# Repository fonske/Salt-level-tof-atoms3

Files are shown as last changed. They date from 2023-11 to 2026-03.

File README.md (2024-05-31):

# Salt-level-tof-atoms3-lite
   Salt level detection brine tank water softener with TOF sensor and AtomS3 lite M5stack
   
   Zoutniveau detectie zoutvat waterontharder met TOF sensor en AtomS3 lite M5stack

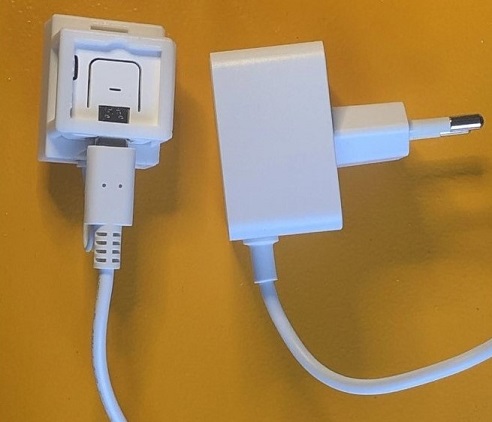
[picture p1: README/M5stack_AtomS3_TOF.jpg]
Example


 ## Dutch:
[README](/README/R_NL.md)

## English:
[README](/README/R_EN.md)

Two branches:

main: VL53L0X sensor

tof2: VL53L1X sensor

## Contact
Purchase: alphonsuijtdehaag at gmail dot com, if you are interested in buying this salt level sensor

Help: Please open a issue on this git project.

"Buy Me A Coffee" (https://www.buymeacoffee.com/ebbenberg)

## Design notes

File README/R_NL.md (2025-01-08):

# Zoutniveau meting met AtomS3 lite en TOF sensor

## Hardware
Er wordt gebruik gemaakt van 
- de [Atom S3 lite](https://www.tinytronics.nl/shop/nl/development-boards/microcontroller-boards/met-wi-fi/m5stack-atom-s3-lite-esp32-s3-development-board) van M5stack
- de [TOF sensor](https://www.tinytronics.nl/shop/nl/platformen-en-systemen/m5stack/unit/m5stack-tof-unit) van M5stack
- optie: [5cm kabeltje](https://www.tinytronics.nl/shop/nl/kabels-en-connectoren/kabels-en-adapters/grove-compatible/m5stack-grove-kabel-5cm-10-stuks) (net iets korter dan meegeleverd wordt met de TOF sensor, per 10st helaas)
- [3D printed](../README/Saltlevel_Atoms3_TOF.stl)  behuizing welke met twee rvs M4 boutjes en moertjes vast gezet kan worden op het deksel van het zout reservoir.

## Software
Alles is in ESPHOME geprogrammeerd.
Eigen wifi gegevens invullen via wifi hotspot met als wachtwoord: configesp

## Lovelace menu
Om het lovelace menu volledig te benutten met de zoutniveau simulatie zoals hieronder in het dashboard te zien is, 
dient er een map /www/images aangemaakt te worden in je home assistant directory.
Kopieer daar alle plaatjes in van [/www/images](../www/images)

Voorbeeld dashboard: 
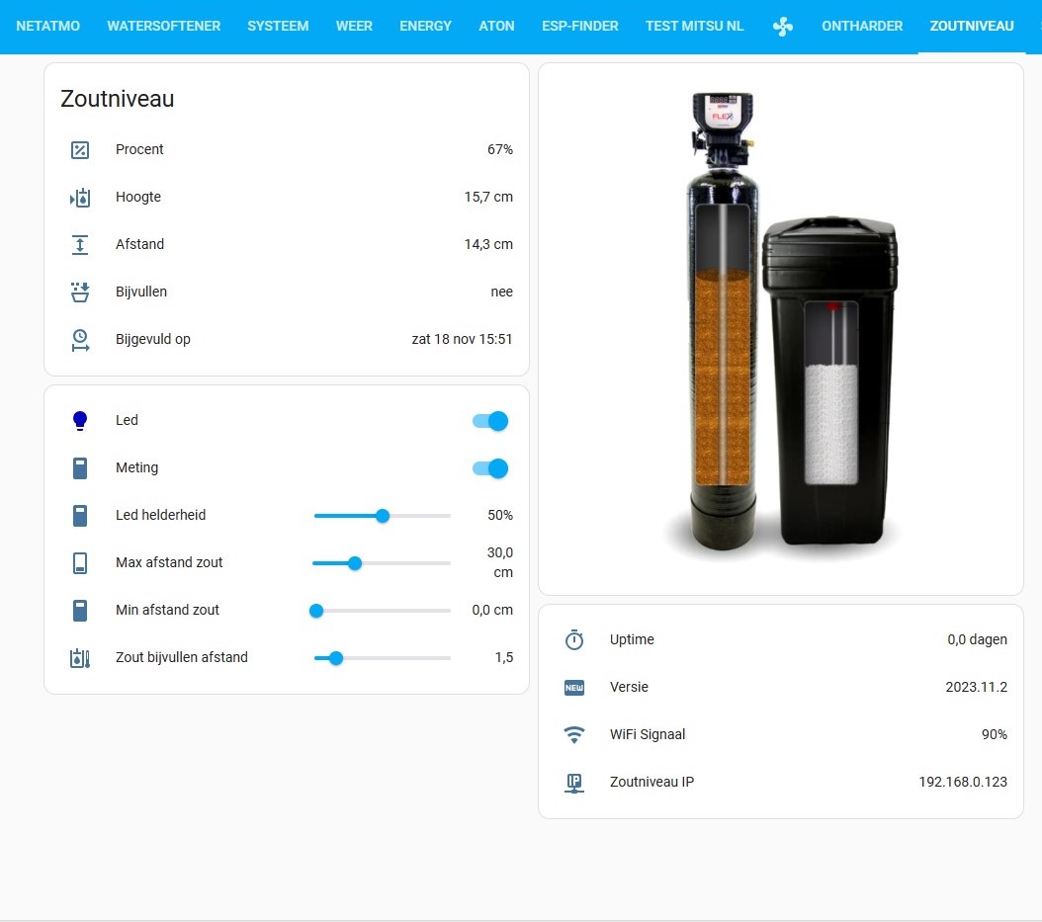
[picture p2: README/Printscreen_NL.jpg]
Example


Het dashboard zelf kan geplaatst worden via home assistant drie puntjes - dashboard bewerken - ruwe configuratie editor
Tekst uit [lovelace_menu_nl.yaml](../home_assistant/lovelace_menu_nl.yaml) daar aan toevoegen en opslaan.
U heeft nu een extra menu Zoutniveau

## Automations
[automation_saltalarm_nl.yaml](../home_assistant/automation_saltalarm_nl.yaml) samenvoegen met automations.yaml (let op inspringingen) of beter:

### Bestand op eigen lokatie: 
[automation_saltalarm_nl.yaml](../home_assistant/automation_saltalarm_nl) op een eigen lokatie zetten:
configuration.yaml aanpassen naar:

```yml
homeassistant:
  packages: !include_dir_named packages
```

Dan directory /packages aanmaken in /config en daar de automation_saltalarm_nl.yaml in kopieren
HA opnieuw starten

## Uitleg werking

Met de schuifregelaars de juiste hoogtes instellen.
Voorbeeld van de minimale en maximale hoogte vind u [hier.](../README/min_max_NL.jpg) 
Zout bijvullen afstand is de afstand vanaf wanneer er een alarm (automation) zal verstuurd worden (waarde van Bijvullen wordt dan "ja")
Dit is gemeten vanaf de onderkant van de tank, dus vanaf de maximale afstand naar boven toe.

Omdat er veel waterontharders zijn waar het water boven het zout staat (klein zoutreservoir), zit er een slimme functie ingebouwd in de afstandmeting
Namelijk, de sensor meet de afstand naar beneden toe. De te meten afstand wordt dan alleen maar groter als het zout op raakt.
Kortere afstanden worden dan ook niet geregistreerd als laatste waarde, enkel langere afstanden. Zo heeft water wat boven het zout uitkomt geen meet invloed meer.
Er zijn 2 registratie: Afstand en Afstand TOF.
Afstand is de meting met de slimme functie. Afstand TOF meet nog steeds continu elke 10 sec maar heeft geen invloed op de procent schaal of berekeningen daaraan.

### LED
De LED op de AtomS3 lite is in of uit te schakelen. Helderheid op 0 is ook LED uit.
De LED verspringt van kleur bij:

0-25% zoutniveau in de tank = ROOD

25-75% zoutniveau in de tank = BLAUW

75-100% zoutniveau in de tank = GROEN

### DRUKKNOP
De drukknop heeft twee functies:
kort ingedrukt (led gaat uit): stop de niveaumeting, handig om zelf even te kijken in het zoutvat.
kort ingedrukt (led gaat aan): zet de niveaumeting weer voort.

Lang ingedrukt (voor 3 sec.). Registreer tijd en datum. Handig om te zien wanneer voor het laatst zout bijgevuld is.
En om de slimme afstand weer te resetten naar 0 en werkelijke meting. Het zout is immers weer bijgevuld

## Noot:
Er is een  [3d print](../README/Saltlevel_Atoms3_TOF.stl)  bestand bijgevoegd om zelf de behuizing te printen.
De behuizing dient met dubbelzijdige tape op het zoutreservoir aan de bovenkant gemonteerd te worden.

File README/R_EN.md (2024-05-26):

# Saltlevel measurement with AtomS3 lite and TOF sensor

## Hardware
The hardware consist of:
- the [Atom S3 lite](https://www.tinytronics.nl/shop/nl/development-boards/microcontroller-boards/met-wi-fi/m5stack-atom-s3-lite-esp32-s3-development-board) from M5stack
- the [TOF sensor](https://www.tinytronics.nl/shop/nl/platformen-en-systemen/m5stack/unit/m5stack-tof-unit) from M5stack
- option: [5cm cable](https://www.tinytronics.nl/shop/nl/kabels-en-connectoren/kabels-en-adapters/grove-compatible/m5stack-grove-kabel-5cm-10-stuks) (a litlle shorter then the original cable delivered with TOF sensor, only per 10 pieces)
- [3D printed](../README/Saltlevel_Atoms3_TOF.stl)  enclosure.

## Software
Everything is coded in ESPHOME
Connecting through wifi hotspot and [IMPROV bluetooth](https://www.improv-wifi.com/) is possible.

## Lovelace menu
For the salt level simulation, as seen in the underneath picture, create a directory /www/images and copy all the images
[/www/images](../www/images) to your home assistant directory

Example dashboard: 
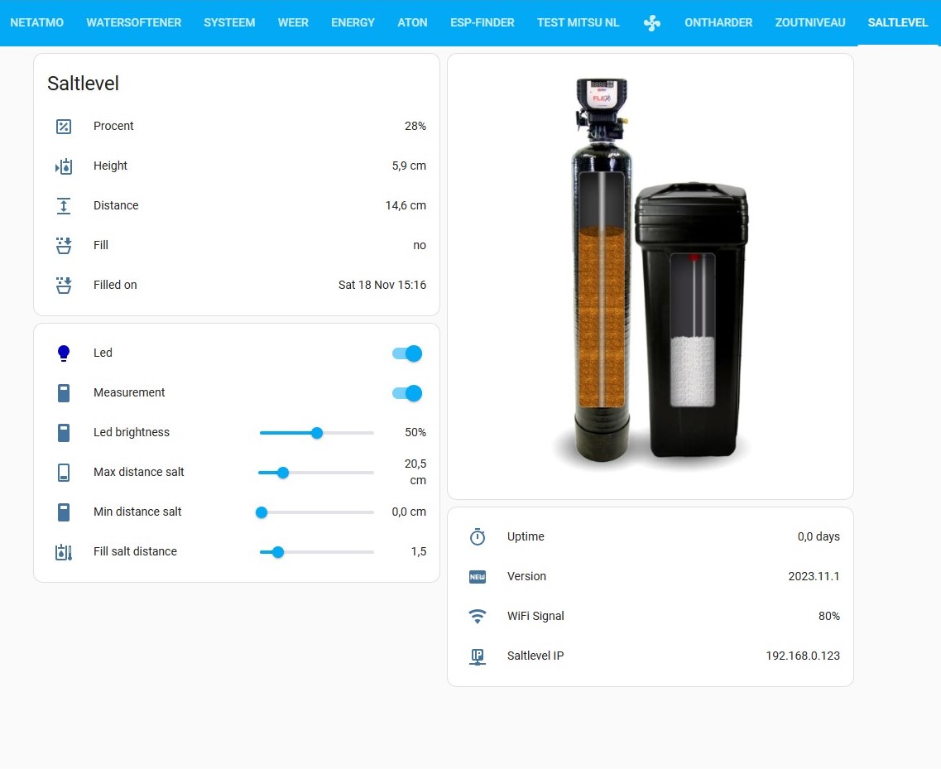
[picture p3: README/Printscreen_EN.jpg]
Example


The dashboard itself can be placed in home assistant by: three dashes - edit dashboard - raw configuration editor
Copy and add the text from [lovelace_menu_nl.yaml](../home_assistant/lovelace_menu_nl.yaml) and click save.
You got now an extra menu Saltlevel

## Automations
[automation_saltalarm_en.yaml](../home_assistant/automation_saltalarm_nl.yaml) combine with automations.yaml (take notice of the indents) or better:

### File on own lokation: 
[automation_saltalarm_en.yaml](../home_assistant/automation_saltalarm_nl) put on own location:
Adjust configuration.yaml to:

```yml
homeassistant:
  packages: !include_dir_named packages
```

Then make directory /packages in /config and copy the automation_saltalarm_nl.yaml to this directory
Restart home assistant.

## Uitleg werking

Met de schuifregelaars de juiste hoogtes instellen.
Voorbeeld van de minimale en maximale hoogte vind u [hier.](../README/min_max_NL.jpg) 
Zout bijvullen afstand is de afstand vanaf wanneer er een alarm (automation) zal verstuurd worden (waarde van Bijvullen wordt dan "ja")
Dit is gemeten vanaf de onderkant van de tank, dus vanaf de maximale afstand naar boven toe.

Omdat er veel waterontharders zijn waar het water boven het zout staat (klein zoutreservoir), zit er een slimme functie ingebouwd in de afstandmeting
Namelijk, de sensor meet de afstand naar beneden toe. De te meten afstand wordt dan alleen maar groter als het zout op raakt.
Kortere afstanden worden dan ook niet geregistreerd als laatste waarde, enkel langere afstanden. Zo heeft water wat boven het zout uitkomt geen meet invloed meer.
Er zijn 2 registratie: Afstand en Afstand TOF.
Afstand is de meting met de slimme functie. Afstand TOF meet nog steeds continu elke 10 sec maar heeft geen invloed op de procent schaal of berekeningen daaraan.

### LED
De LED op de AtomS3 lite is in of uit te schakelen. Helderheid op 0 is ook LED uit.
De LED verspringt van kleur bij:

0-25% zoutniveau in de tank = ROOD

25-75% zoutniveau in de tank = BLAUW

75-100% zoutniveau in de tank = GROEN

### DRUKKNOP
De drukknop heeft twee functies:
kort ingedrukt (led gaat uit): stop de niveaumeting, handig om zelf even te kijken in het zoutvat.
kort ingedrukt (led gaat aam): zet de niveaumeting weer voort.

Lang ingedrukt (voor 3 sec.). Registreer tijd en datum. Handig om te zien wanneer voor het laatst bijgevuld is.
En om de slimme afstand weer te resetten naar 0 en werkelijke meting. Het zout is immers weer bijgevuld

## Noot:
Er is een  [3d print](../README/Saltlevel_Atoms3_TOF.stl)  bestand bijgevoegd om zelf de behuizing te printen.
De behuizing dient met dubbelzijdige tape op het zoutreservoir aan de bovenkant gemonteerd te worden.

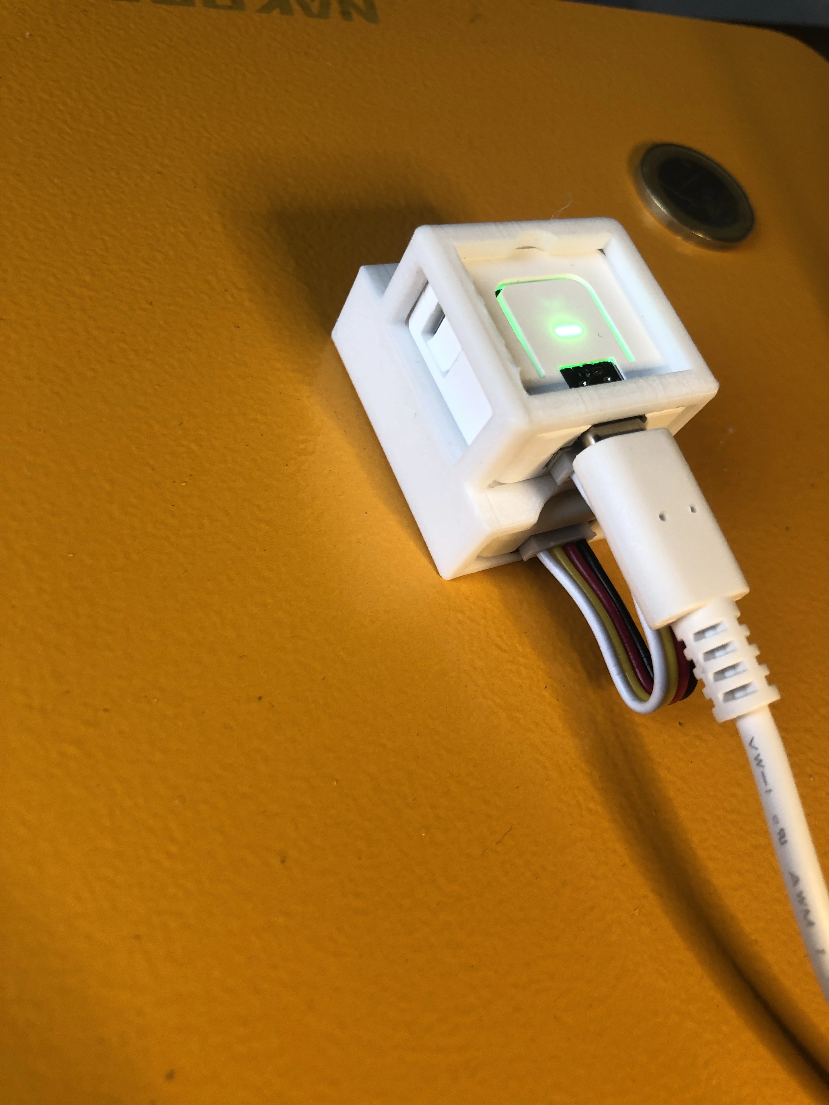
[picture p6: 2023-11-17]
README/sensor_img_3.jpg

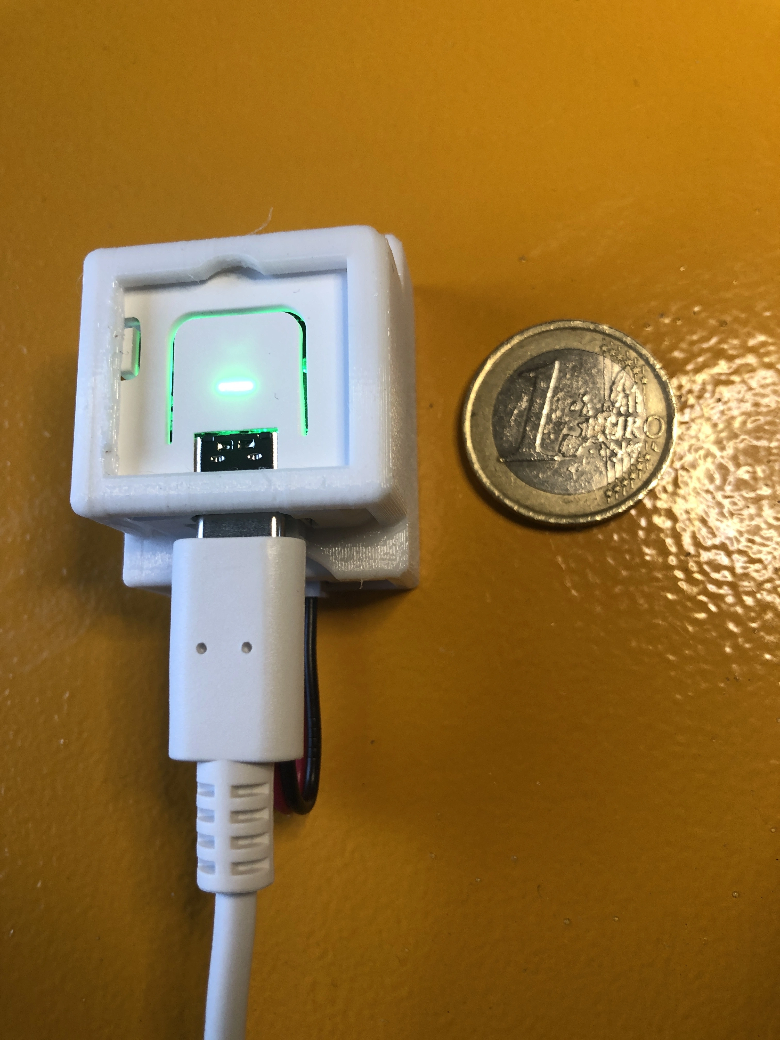
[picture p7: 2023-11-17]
README/sensor_img_4.jpg

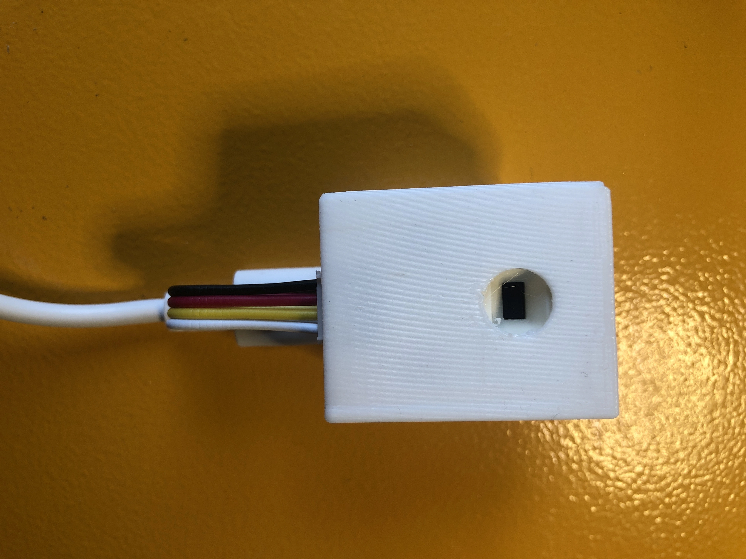
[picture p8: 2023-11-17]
README/sensor_img_2.jpg

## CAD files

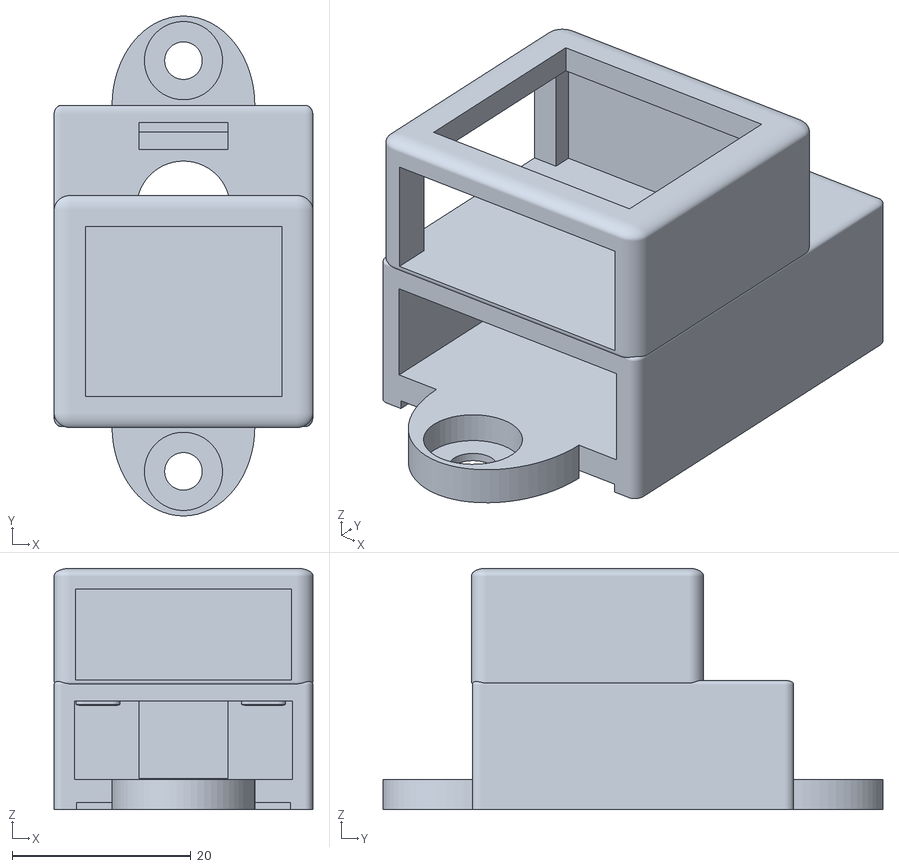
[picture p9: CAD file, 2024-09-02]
README/Saltlevel Atom TOF holder with mounting eyes.stl
29.0 x 56.0 x 27.0

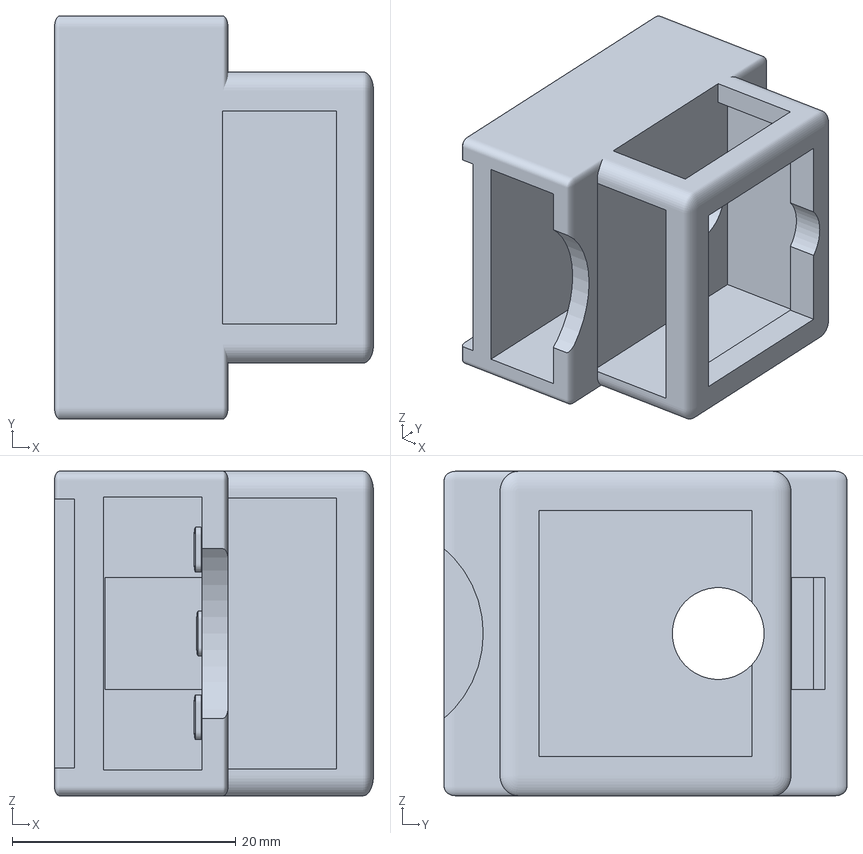
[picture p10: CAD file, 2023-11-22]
README/Saltlevel_Atoms3_TOF_3M_VHB_4991F.3mf
28.5 x 36.0 x 29.0 mm

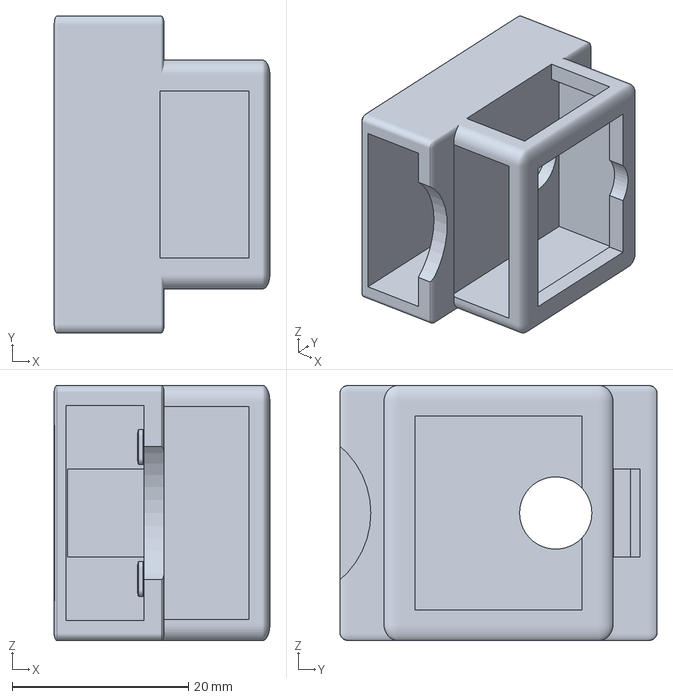
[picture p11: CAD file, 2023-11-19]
README/Saltlevel_Atoms3_TOF.3mf
24.5 x 36.0 x 29.0 mm

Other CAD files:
README/Saltlevel_Atoms3_TOF.stl
README/Saltlevel_Atoms3_TOF_3M_VHB_4991F.stl

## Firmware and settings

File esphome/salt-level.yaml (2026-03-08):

substitutions:
  device_description: "Salt level detection with M5Stack AtomS3 lite and TOF vl53l0x sensor"
  timezone: "Europe/Amsterdam"

## choose between languages. NL or EN are available.
packages:
  remote_package:
    url: https://github.com/fonske/Salt-level-tof-atoms3
    ref: main
    refresh: 0s
    files: [
            esphome/labels/.salt-level-labels-nl.yaml,  
            #esphome/labels/.salt-level-labels-en.yaml, 
           ]
## choices are: esphome/labels/.salt-level-labels-en.yaml, or esphome/labels/.salt-level-labels-nl.yaml,

## for developing/testing, uncomment local includes and comment out remote_package part.
#packages:
#  substitutions: !include labels/.salt-level-labels-nl.yaml
#  substitutions: !include labels/.salt-level-labels-en.yaml

esphome:
  name: ${name}
  friendly_name: ${friendly_name}
  name_add_mac_suffix: false
  on_boot:
    priority: 200
    then:
      - script.execute: on_boot

esp32:
  board: esp32-s3-devkitc-1
  framework:
    type: arduino

wifi:
  ssid: !secret wifi_ssid
  password: !secret wifi_password
  #fast_connect: true

  # Enable fallback hotspot (captive portal) in case wifi connection fails
  ap:
    ssid: ${name}
    password: "configesp"
    ap_timeout: 30s
 
captive_portal:

# Sync time with sntp server
time:
  - platform: homeassistant
    id: sntp_time
    timezone: ${timezone}

# Enable logging
logger:
  baud_rate: 0
  logs:
    esp32.preferences: DEBUG
    sensor: DEBUG
    text_sensor: DEBUG
    switch: DEBUG
    button: DEBUG
    number: DEBUG
    component: ERROR

# Enable Home Assistant API
api:
  reboot_timeout: 0s
  services:
    - service: set_last_distance
      variables:
        last_distance_value: int
      then:
        - globals.set:
            id: last_distance
            value: !lambda 'return last_distance_value;' 
 
#update for esphome 2024.6.0
# OTA:
ota:
  platform: esphome
  
web_server:
  port: 80

i2c:
  - id: bus_a
    sda: GPIO2
    scl: GPIO1

# Define a global variable for last regeneration time
globals:
  - id: fill_last
    type: std::string
    restore_value: yes
    initial_value: '"${never}"'

  - id: last_distance
    type: float
    restore_value: yes
    initial_value: '0.00'

script:
###  On reboot or powerloss of the esp, set the fill last date and time
  - id: on_boot
    then:
      - delay: 5s
      - text_sensor.template.publish:
          id: salt_fill_last
          state: !lambda |-
            return id(fill_last);
      - switch.turn_on: salt_fill_switch
      - light.turn_on: led
      - sensor.template.publish:
          id: salt_distance
          state: !lambda |-
            return id(distance_cm).state;
  - id: recalculate
    then:
      - sensor.template.publish:
          id: salt_height
          state: !lambda |-
            return id(salt_height_max).state-id(last_distance_cm).state;
      - sensor.template.publish:
          id: salt_procent
          state: !lambda |-
            const float max_distance = id(salt_height_max).state; // heigt in cm to lowest level
            const float min_distance = id(salt_height_min).state; // height in cm to highest level
            return int((1/((max_distance - min_distance)/id(salt_height).state))*100);
      - text_sensor.template.publish:
          id: salt_fill_salt
          state: !lambda |-
            if (id(salt_height).state < id(salt_height_fill).state) {
              return {"${salt_fill_yes}"};
            } else {
              return {"${salt_fill_no}"};
             }

sensor:
  - platform: template
    id: last_distance_cm
    name: ${salt_distance}
    icon: mdi:ruler
    unit_of_measurement: cm
    accuracy_decimals: 1
    update_interval: never

  - platform: vl53l0x
    id: distance_cm
    name: ${salt_distance} TOF
    address: 0x29
    update_interval: 10s
    long_range: false
    internal: false
    icon: mdi:ruler
    filters:
      - lambda: |-
          if (isnan(x)) {
            return 0;
          } else {
            return x;
          }
      - lambda: return x*100;
      - clamp:
          min_value: 0.0
          max_value: 400.0
    on_value:
      then:
        - if:
            condition:
              switch.is_on: salt_fill_switch
            then:          
            - sensor.template.publish:
                id: salt_distance
                state: !lambda |-
                  return id(distance_cm).state;
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

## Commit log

2023-11-19 3d files
    [Saltlevel_Atoms3_TOF.3mf, Saltlevel_Atoms3_TOF.stl]
2023-11-22 updated 3dprint
    [Saltlevel_Atoms3_TOF_3M_VHB_4991F.3mf, Saltlevel_Atoms3_TOF_3M_VHB_4991F.stl]
2024-09-02 Create Saltlevel Atom TOF holder with mounting eyes.stl
    [Saltlevel Atom TOF holder with mounting eyes.stl]
